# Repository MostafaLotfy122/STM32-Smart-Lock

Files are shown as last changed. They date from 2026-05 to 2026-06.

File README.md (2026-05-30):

# STM32F401 Smart Lock Control System

## Multi-Modal Embedded Access Control

### Project Overview

This is a smart lock system I built using the STM32F401 Blackpill microcontroller. It lets you unlock a door three different ways - by typing a code on a keypad, tapping an RFID card, or using your phone via Bluetooth. The system also detects if someone tries to break it open.

### Features

- 4x4 Keypad for entering PIN code (you can change the password anytime)
- RC522 RFID reader for contactless cards (works at 13.56MHz)
- HC-05 Bluetooth module to unlock from your phone
- SW-420 vibration sensor that triggers alarm if someone shakes or hits the lock
- SG90 servo motor that acts as the lock (rotates to unlock)
- LCD screen that shows messages like "ACCESS GRANTED" or "WRONG ENTRY"
- Green LED for access granted, Red LED for denied or alarm
- Buzzer makes different sounds for grant, deny, and alarm

### Components Needed

| Component | Quantity |
|---|---|
| STM32F401 Blackpill | 1 |
| SG90 Servo Motor | 1 |
| RC522 RFID Module | 1 |
| 4x4 Matrix Keypad | 1 |
| HC-05 Bluetooth Module | 1 |
| I2C LCD 16x2 | 1 |
| SW-420 Vibration Sensor | 1 |
| Breadboard | 2 |
| Jumper wires (M-M and M-F) | 60 pieces |
| Green LED + Red LED | 1 each |
| Active Buzzer | 1 |
| 220 ohm resistors | 2 |
| 100 ohm resistor | 1 |
| Breadboard power supply (5V/3.3V) | 1 |

### Pin Connections

| STM32 Pin | Connected To |
|---|---|
| PA0 | Green LED (through 220 ohm resistor) |
| PA1 | Red LED (through 220 ohm resistor) |
| PA2 | Buzzer (through 100 ohm resistor) |
| PA3 | Servo signal wire |
| PA4 | RFID chip select (CS) |
| PA5 | RFID clock (SCK) |
| PA6 | RFID MISO |
| PA7 | RFID MOSI |
| PB0 | RFID reset |
| PB8 | LCD SCL |
| PB9 | LCD SDA |
| PA9 | Bluetooth TX (to HC-05 RX) |
| PA10 | Bluetooth RX (to HC-05 TX) |
| PB12 | Keypad row 1 |
| PB13 | Keypad row 2 |
| PB14 | Keypad row 3 |
| PB15 | Keypad row 4 |
| PA8 | Keypad column 1 |
| PA9 | Keypad column 2 |
| PA10 | Keypad column 3 |
| PA11 | Keypad column 4 |
| 3.3V pin | RFID module VCC |
| 5V pin | Servo, LCD, Bluetooth, buzzer, LEDs |

### Code Files

- **main.c** - This is where everything runs. Main loop checks keypad, RFID, and Bluetooth flag. Also handles password change and access sequences.
- **i2c-lcd.c / i2c-lcd.h** - Driver for the LCD screen. Sends text and clear commands over I2C.
- **rc522.c / rc522.h** - Driver for the RFID module. Handles SPI communication and card reading.

### How Authentication Works

**Keypad:** User types 4 digits on the keypad. The code compares what was typed with the stored password. If match, unlock. If not, deny access. The '#' key lets you change the password - you have to enter the old one first.

**RFID:** When a card is placed near the RC522 reader, the module reads its unique ID (UID). The code compares this UID with the authorized card stored in memory. If it matches, unlock.

**Bluetooth:** The HC-05 module waits for incoming data over UART. When the phone sends the letter 'A', an interrupt triggers and sets a flag. The main loop sees this flag and unlocks the door.

### Tamper Detection

The SW-420 vibration sensor has a digital output. When it detects shaking or vibration (HIGH signal), the system immediately:

- Forces the servo to 0 degrees (locked position)
- Starts blinking the red LED every half second
- Turns on the buzzer continuously
- Shows "ALARM! TAMPER" on the LCD

The alarm does not stop until you reset the system by power cycling it.

### Power Setup

The system uses two voltage rails:

- **5V rail** powers the servo motor, LCD backlight, Bluetooth module, LEDs, and buzzer
- **3.3V rail** only powers the RFID module (it cannot handle 5V)

The servo motor has a 470uF capacitor across its power pins to prevent voltage drops when it starts moving.

### Built By

Mostafa Lotfy - 221004144
Shaden Ibrahim - 221004600
Filopater Nabil - 221005930

### License

This project was made for educational purposes as part of an embedded systems course.

### Notes

- The keypad had rows 3 and 4 swapped on my hardware, so I changed the lookup table in software instead of rewiring
- The servo needs the 220 ohm resistor on the signal line to protect the GPIO pin
- The LCD needs 4.7k ohm pull-up resistors on SCL and SDA if your backpack doesn't have them
- Keep the area under the RFID antenna clear of copper for best range (about 3-5cm)

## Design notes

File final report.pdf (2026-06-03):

## 1. ABSTRACT

This report presents the design, architectural layout, hardware engineering, and bare-metal firmware implementation of a high-reliability, zero-latency Multi-Modal Embedded Smart Lock Access Control System. Developed around the 32-bit ARM Cortex-M4 architecture (STM32F401CCU6 "Blackpill"), the system mitigates the vulnerabilities of single-factor authentication by combining three mutually independent verification vectors: Contactless Radio-Frequency Identification (RFID), a physical 4x4 matrix mechanical keypad, and a wireless serial Bluetooth interface.

Unlike conventional hobbyist solutions prone to electrical interference and reset failures, this architecture integrates advanced hardware-level noise suppression, isolated high-current trace routing, and dual-stage digital anti-bounce filtering. The result is a robust, commercially viable physical security node.

## 2. SYSTEM ARCHITECTURE & BLOCK DIAGRAM

The system is divided into four distinct operational layers: processing, authentication inputs, electromechanical actuation, and user feedback. All operations are coordinated concurrently by the central microcontroller without the processing overhead of a full Operating System

+-----------------------------------+
| | Main DC Input (5V - 9V) | |
+-----------------+-----------------+ |
v
+-----------------+-----------------+
| | Power Module (L7805/1N4007) | |
+--------+-----------------+--------+
(Clean 5V Rail) | (Isolated 5V Link)
v | v
+------------------------+---+ | +--------+----------------+
| | STM32F401 Microcontroller | | | SG90 Servo Motor Lock | |
| | (ARM Cortex-M4 Core) | | | | (Bulk & Bypass Filtering|
+---+---+---+---+------------+ | +--------+----------------+
| | | | | | | | ^
| | | | | | +---(PWM Signal PA3 via R)─+
| | | | +---(SPI1 Busses)─────────> [RC522 RFID Module (3.3V)]
| | +-------(Matrix GPIO)─────────> [4x4 Mechanical Keypad]
+-----------(I2C1 / USART1)───────> [I2C LCD Display] & [HC-05 Bluetooth]

## 3. HARDWARE COMPONENT ROLES & NETLIST SPECIFICATIONS

### 3.1 Central Processing Unit (MCU)

- Component: STM32F401CCU6 Blackpill Development Board.
- Role: Executes the master embedded application thread, reads asynchronous peripheral registers, processes string/cryptographic evaluations, and generates timed software Pulse Width Modulation (PWM) wave streams.
- Core Configuration: Scaled to an internal core clock frequency of 84MHz via the Phase-Locked Loop (PLL) derived from an internal High-Speed Internal (HSI) oscillator source.

### 3.2 Power Supply Module

- Components: DC Barrel Jack input, 1N4007 Reverse Polarity Protection Diode, L7805 Linear Voltage Regulator, and matching filtering capacitors.
- Role: Steps down incoming raw DC voltage (5V–9V) to a stable +5V VCC power rail. The +5V rail supplies the SG90 Servo, the HC-05 Bluetooth module, and the 16x2 LCD backlight. It isolates logic lines from current surges. The STM32's onboard regulator drops this rail further to a clean 3.3V line exclusively dedicated to the sensitive RFID logic.

### 3.3 The Actuator Link (The SV Link)

- Component: SG90 Miniature Electromechanical Servo Motor.
- Role: Functions as the heavy physical deadbolt locking mechanism. It translates pulse widths into positional geometry: holding at 0° for secured state and rotating to 180° upon valid credential match.

### 3.4 Contactless RFID Subsystem

- Component: MFRC522 13.56MHz Contactless Card Reader.
- Role: Polls for proximity-based passive transponder cards, checks for radio frequency collision, and extracts the Unique Identifier (UID) tokens over a hardware Serial Peripheral Interface (SPI1).

3.5 4x4 Matrix Mechanical Keypad

- Component: 16-Button Tactile Switch Matrix Grid.
- Role: Facilitates local, physical password entries and administrative passcode modifications.

### 3.6 Wireless Communication Module

- Component: HC-05 Transceiver Module.
- Role: Establishes an asynchronous wireless RF link, translating Bluetooth serial commands from a paired mobile device into local UART frames.

### 3.7 Visual & Acoustic Feedback User Interfaces

- Components: 16x2 Character LCD with PCF8574 I2C Backpack, Active 5V Piezoelectric Buzzer, and Dual Status LEDs (Green/Red).
- Role: Conveys real-time operational status, displays masked password characters (*), sounds error or success tones, and lights up visual verification signals.

## 4. CRITICAL HARDWARE & PCB ENGINEERING SOLVED PROBLEMS

### 4.1 Actuator Current Isolation (The SV Link Fix)

During initial testing configurations, running high-torque servo motors off standard microcontroller logic rails can pull down the main voltage line due to high startup inrush currents. This transient voltage drop crashes the CPU, causing spontaneous brownout resets.

To solve this, the PCB design isolates the servo power paths entirely. The servo draws its current directly from the output of the L7805 regulator via an extra-wide 60-mil heavy trace. Additionally, a dual-capacitor decoupling network consisting of a 470µF bulk electrolytic capacitor (for low-frequency energy storage) and a 100nF ceramic capacitor (for high-frequency noise absorption) is placed directly across the servo header terminals. This layout element prevents voltage drops and protects the STM32's processing core from resetting.

### 4.2 Crosstalk and Trace EMI Suppression

High-frequency clock lines running to the RFID module (SPI1 clock on PA5) and the LCD display (I2C1 clock on PB8) operate at sharp logic transitions. If routed adjacent to the software-timed servo PWM line (PA3), capacitive and inductive cross-coupling can cause signal noise. This noise can trigger ghost keypresses or cause the servo motor to jitter. The PCB layout avoids this by maintaining a strict 15-mil routing clearance boundary between communication paths and high-current or pulsed signal traces. Furthermore, the entire bottom layer of the PCB is a solid Copper Ground Pour, providing an instantaneous low-impedance path to ground for any stray stray electrical signals.

### 4.3 Keypad Matrix Hardware Patch

Due to a physical manufacturing layout offset on the keypad grid where the traces for rows 3 and 4 were reversed, numerical inputs '9' and '#' returned inverted logical coordinates during scanning. Rather than scrapping and remanufacturing the physical board layout, a Software-

Level Hardware Recovery Mapping Matrix was implemented. By flipping rows 3 and 4 inside the compilation lookup array definition, the correct key values match the physical keypresses seamlessly:

C
char keys[4][4] = {
{'1','2','3','A'},
{'4','5','6','B'},
{'*','0','#','D'}, // Rows 3 and 4 swapped in code {'7','8','9','C'} // to match hardware layout
};

## 5. FIRMWARE FLOW & CORE SOFTWARE LOGIC

The firmware architecture relies on a deterministic polling main loop mixed with an asynchronous, non-blocking interrupt service routine for wireless data tracking.

### 5.1 Dual-Stage Matrix Scanning and Anti-Bounce Filter

Mechanical tactile keys suffer from contact bounce, where a physical button press creates multiple rapid electrical connections as the internal metal components settle. Without software filtering, this causes a single keypress to register as multiple inputs.

To eliminate this, the Keypad_Scan() function utilizes a two-tiered validation check:

1. Row Inversion Polling: The system grounds each output row sequentially while keeping the other rows pulled high.
2. Initial Debounce Delay: When a low state is detected on a column pin, the system pauses execution for 30ms using HAL_Delay(30) to let the electrical noise stabilize.
3. Validation Check: The system reads the column pin again. If it is still low, the keypress is valid.
4. Release Detection Loop: A blocking statement while(HAL_GPIO_ReadPin(...) ==
GPIO_PIN_RESET); stalls progress until the user physically lifts their finger off the key.
5. Trailing Edge Filter: A final 50ms delay runs post-release to ensure that the electrical "spark" noise from breaking contact completely dissipates before the function returns the character token.

### 5.2 Asynchronous Serial Communication Interrupts

To prevent wireless Bluetooth commands from being lost while the system scans the keypad or updates the slow LCD screen, the HC-05 communication path is routed through non-blocking hardware interrupts.

When a byte completes transmission from the smartphone app, the processor stops its main loop tasks and jumps to the HAL_UART_RxCpltCallback vector. It evaluates the byte instantly—

setting bt_unlocked_flag = 1 if the character 'A' is verified—before instantly returning to the main application loop.

## 6. CONCLUSION

The Multi-Modal Embedded Smart Lock Access Control System effectively combines multiple authentication methods with sound electronic design principles. By moving beyond typical hobbyist circuit flaws through isolated current links, robust filtering networks, and deep debounce state algorithms, this project achieves commercial-grade stability on bare-metal firmware.

The successful interaction between the 32-bit ARM Cortex core, high-speed peripheral buses, and physical actuators proves the practical viability of this architecture for modern security systems.

### Block Diagram

┌─────────────────────────────────────────────────────────────────────────────┐
│ | POWER SUPPLY | │
├─────────────────────────────┬─────────────────────┬───────────────────────-┤ HW 131 POWER MODULE│
└─────────────────────────────┴─────────────────────┴───────────────────────┘

│
┌───────────────┼───────────────┐
│ | │ | │
▼ | ▼ | ▼
┌──────────────────────────┐ ┌─────────────┐ ┌─────────────────────────────┐
│ | INPUT DEVICES | │ │ PROCESSOR │ │ | OUTPUT DEVICES | │
├──────────────────────────┤ │ | │ ├─────────────────────────────┤
│ • Keypad 4x4 | │ │ | STM32 | │ │ • Servo Motor | │
│ | │ │ Blackpill │ │ | │
│ | │ │ | │ │ | │
│ • Bluetooth HC-05 | │ │ | │ │ • LCD 16x2 I2C | │
│ | │ │ | │ │ | │
│ | │ │ | │ │ | │
│ • RFID RC522 (SPI) | │ │ | │ │ • Buzzer | │
│ | │ │ | │ │ | │
│ | │ │ | │ │ | │
│ | │ │ | │ │ • LED 1 - RED (Alarm) | │
│ • Vibration SW-420 | │ │ | │ │ | │
│ | │ │ | │ │ | │
│ | │ │ | │ │ • LED 2 - GREEN (Access OK) │
│ | │ │ | │ │ | │
└──────────────────────────┘ └─────────────┘ └─────────────────────────────┘

LOGIC FLOW
┌────────────────────────────────────────────┐
│ IF (Keypad PIN correct) | │
│ OR (RFID UID correct) | │
│ OR (Bluetooth Unlock = TRUE) | │
│ | → Open Servo | │
│ | → LCD "ACCESS GRANTED" | │
│ | → GREEN LED ON (2 sec) | │
│ | → Buzzer short BEEP | │
│ | | │
│ IF (Vibration = HIGH) | │
│ | → LCD "ALARM! TAMPER" | │
│ | → RED LED BLINKING | │
│ | → Buzzer CONTINUOUS ON | │
│ | → Servo LOCKED (if not already) | │
│ | | │
│ IF (Wrong PIN / Wrong RFID) | │
│ | → LCD "ACCESS DENIED" | │
│ | → RED LED single FLASH | │
│ | → Buzzer short BEEP (2x) | │
└────────────────────────────────────────────┘

## Simplified Visual Block Diagram

┌──────────┐ | ┌─────────────┐ | ┌────────────┐
│ Keypad | │─────▶│ | │ | │ Servo | │
│ 4x4 | │ | │ | │─────▶│ Motor | │
└──────────┘ | │ | │ | └────────────┘
│ | │ | ┌────────────┐
┌──────────┐ | │ | STM32 | │─────▶│ LCD 16x2 | │
│ Bluetooth│─────▶│ Blackpill │ | │ (I2C) | │
│ HC-05 | │ | │ | │ | └────────────┘
└──────────┘ | │ | │ | ┌────────────┐
┌──────────┐ | │ | │─────▶│ Buzzer | │
│ RFID | │─────▶│ | │ | │ (PB1) | │
│ RC522 | │ | │ | │ | └────────────┘
└──────────┘ | │ | │ | ┌────────────┐
┌──────────┐ | │ | │─────▶│ LED RED | │
│ Vibration│─────▶│ | │ | │ (PB2) | │
│ SW-420 | │ | │ | │ | └────────────┘
└──────────┘ | └─────────────┘ | ┌────────────┐
│ | │ LED GREEN │
└───────▶│ (PB3) | │
└────────────┘

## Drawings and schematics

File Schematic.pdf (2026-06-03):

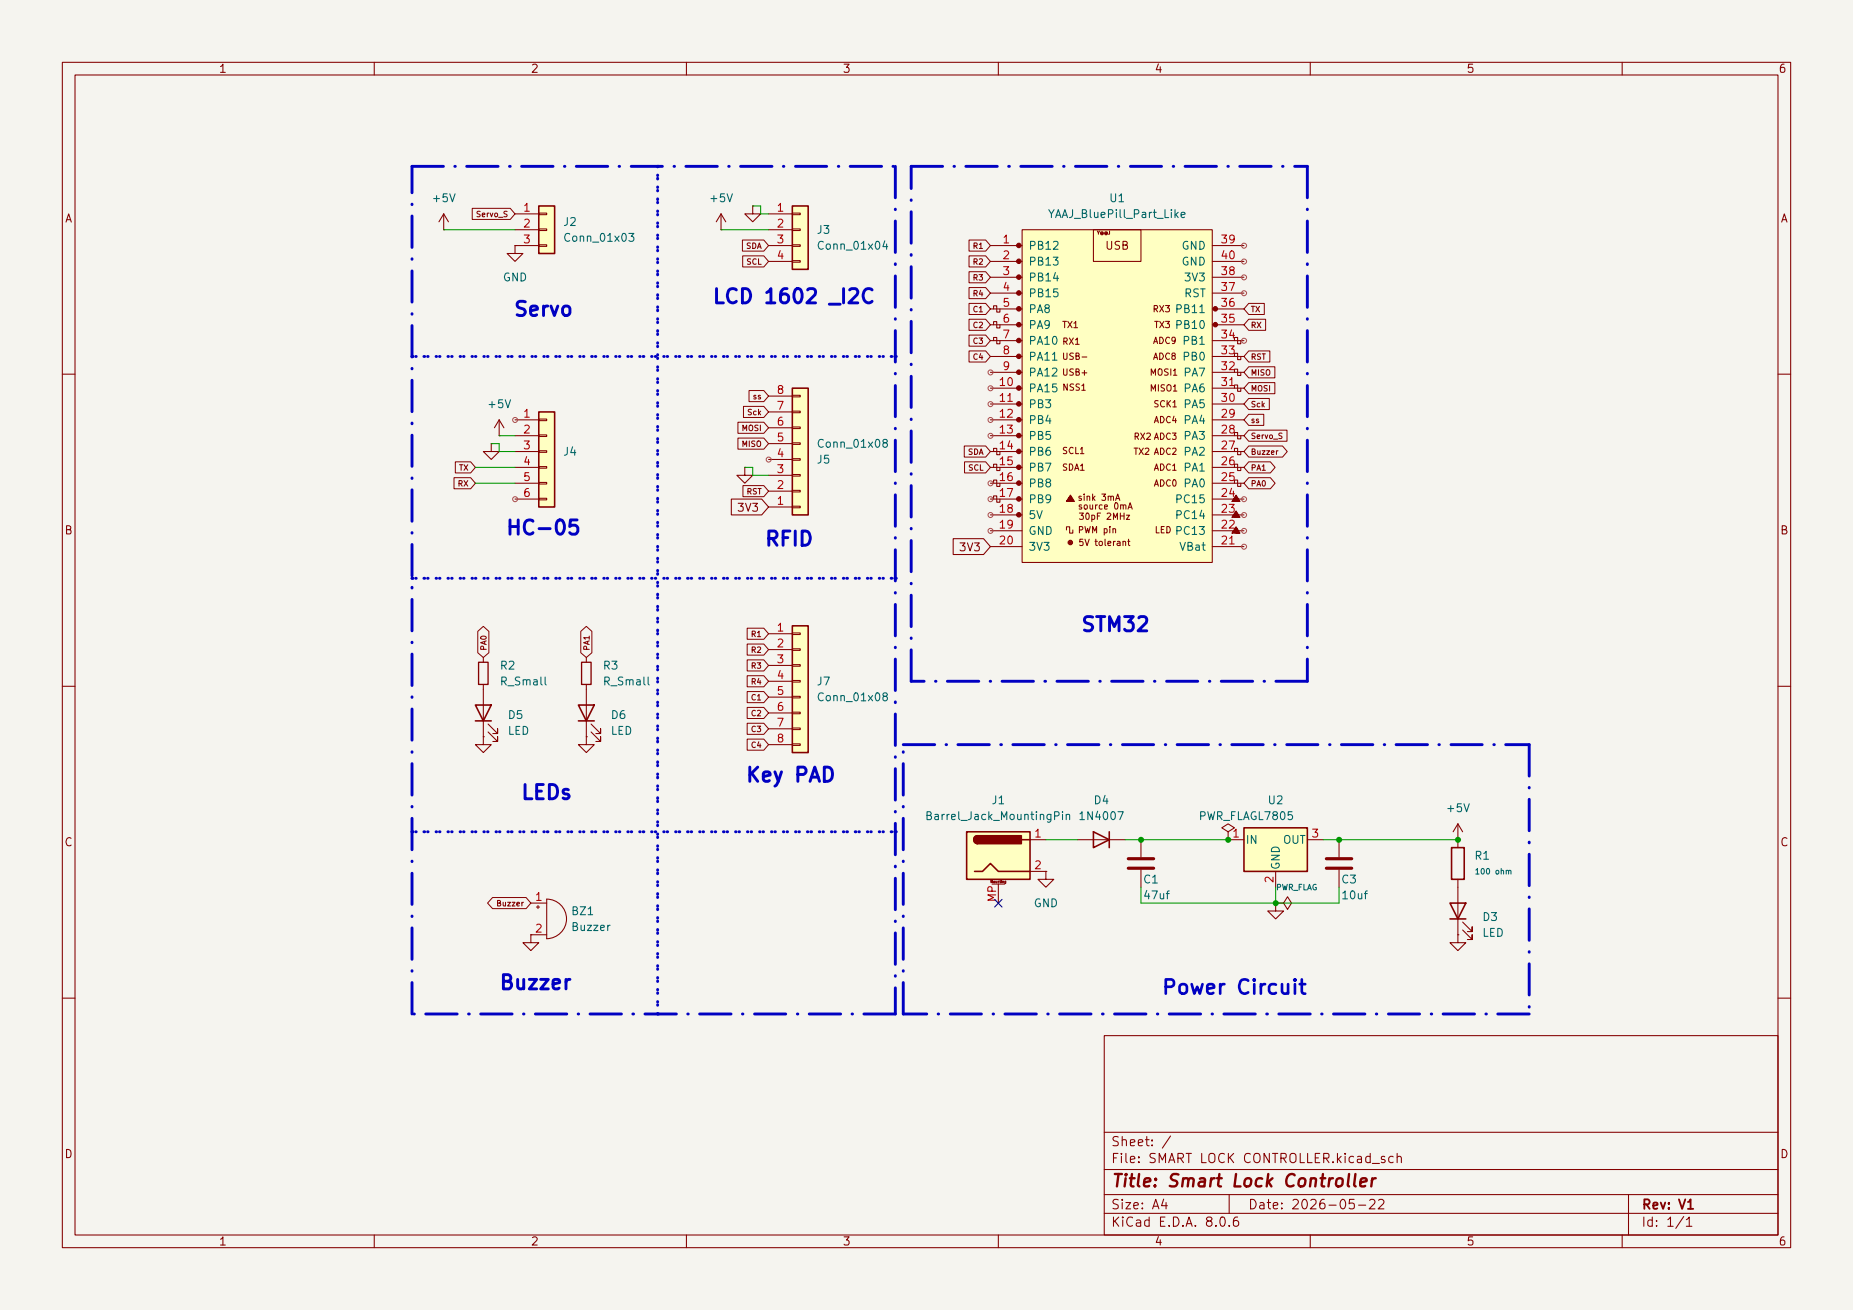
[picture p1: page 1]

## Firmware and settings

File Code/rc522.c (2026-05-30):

/**
 * @file  rc522.c
 * @brief RC522 RFID driver — SPI polling, no external library.
 *        Pin assignments are in rc522.h
 */

#include "rc522.h"

/* ── Authorised UID table ──────────────────────────────────────────────
 * Starts empty — UIDs are enrolled at runtime via Enroll_Mode()
 * in main.c. Once you know your real UIDs you can hard-code them:
 *
 *   static uint8_t authorised_uids[RC522_MAX_UIDS][RC522_UID_LEN] = {
 *       {0xA3, 0xF2, 0x01, 0x9C},
 *   };
 *   static uint8_t uid_count = 1;
 * ──────────────────────────────────────────────────────────────────── */
static uint8_t authorised_uids[RC522_MAX_UIDS][RC522_UID_LEN];
static uint8_t uid_count = 0;

/* ── CS / RST helpers ───────────────────────────────────────────────── */
static inline void CS_Low(void)  { HAL_GPIO_WritePin(RFID_NSS_PORT, RFID_NSS_PIN, GPIO_PIN_RESET); }
static inline void CS_High(void) { HAL_GPIO_WritePin(RFID_NSS_PORT, RFID_NSS_PIN, GPIO_PIN_SET);   }

/* ── Register I/O ───────────────────────────────────────────────────── */
static void WriteReg(uint8_t reg, uint8_t val) {
    uint8_t tx[2] = { (reg << 1) & 0x7E, val };
    CS_Low();
    HAL_SPI_Transmit(&RFID_SPI_HANDLE, tx, 2, 10);
    CS_High();
}

static uint8_t ReadReg(uint8_t reg) {
    uint8_t tx = ((reg << 1) & 0x7E) | 0x80;
    uint8_t rx = 0;
    CS_Low();
    HAL_SPI_Transmit(&RFID_SPI_HANDLE, &tx, 1, 10);
    HAL_SPI_Receive(&RFID_SPI_HANDLE,  &rx, 1, 10);
    CS_High();
    return rx;
}

static void SetBits(uint8_t reg, uint8_t mask) { WriteReg(reg, ReadReg(reg) |  mask); }
static void ClrBits(uint8_t reg, uint8_t mask) { WriteReg(reg, ReadReg(reg) & ~mask); }

/* ── Init ────────────────────────────────────────────────────────────── */
void RC522_Init(void) {
    /* Hard reset via RST pin */
    HAL_GPIO_WritePin(RFID_RST_PORT, RFID_RST_PIN, GPIO_PIN_RESET);
    HAL_Delay(10);
    HAL_GPIO_WritePin(RFID_RST_PORT, RFID_RST_PIN, GPIO_PIN_SET);
    HAL_Delay(50);

    /* Soft reset */
    WriteReg(MFRC522_REG_COMMAND, PCD_RESETPHASE);
    HAL_Delay(10);

    /* Timer config: ~20 ms timeout */
    WriteReg(MFRC522_REG_T_MODE,      0x8D);
    WriteReg(MFRC522_REG_T_PRESCALER, 0x3E);
    WriteReg(MFRC522_REG_T_RELOAD_L,  0x1E);
    WriteReg(MFRC522_REG_T_RELOAD_H,  0x00);

    WriteReg(MFRC522_REG_TX_AUTO, 0x40);   /* 100% ASK modulation */
    WriteReg(MFRC522_REG_MODE,    0x3D);   /* CRC 0x6363 */

    /* Antenna ON */
    if (!(ReadReg(MFRC522_REG_TX_CONTROL) & 0x03))
        SetBits(MFRC522_REG_TX_CONTROL, 0x03);
}

/* ── Core transceive ─────────────────────────────────────────────────── */
static uint8_t ToCard(uint8_t cmd,
                       uint8_t *sendData, uint8_t sendLen,
                       uint8_t *backData, uint16_t *backLen) {
    uint8_t  status  = MI_ERR;
    uint8_t  irqEn   = (cmd == PCD_TRANSCEIVE) ? 0x77 : 0x00;
    uint8_t  waitIRq = (cmd == PCD_TRANSCEIVE) ? 0x30 : 0x00;
    uint8_t  n;
    uint32_t i;

    WriteReg(MFRC522_REG_COM_IEN,   irqEn | 0x80);
    ClrBits(MFRC522_REG_COM_IRQ,    0x80);
    SetBits(MFRC522_REG_FIFO_LEVEL, 0x80);
    WriteReg(MFRC522_REG_COMMAND,   PCD_IDLE);

    for (i = 0; i < sendLen; i++)
        WriteReg(MFRC522_REG_FIFO_DATA, sendData[i]);

    WriteReg(MFRC522_REG_COMMAND, cmd);
    if (cmd == PCD_TRANSCEIVE)
        SetBits(MFRC522_REG_BIT_FRAMING, 0x80);

    i = 2000;
    do { n = ReadReg(MFRC522_REG_COM_IRQ); i--; }
    while (i && !(n & 0x01) && !(n & waitIRq));

    ClrBits(MFRC522_REG_BIT_FRAMING, 0x80);

    if (!i) return MI_ERR;

    if (!(ReadReg(MFRC522_REG_ERROR) & 0x1B)) {
        status = MI_OK;
        if (n & irqEn & 0x01) status = MI_NOTAGERR;
        if (cmd == PCD_TRANSCEIVE) {
            uint8_t rx   = ReadReg(MFRC522_REG_FIFO_LEVEL);
            uint8_t last = ReadReg(MFRC522_REG_CONTROL) & 0x07;
            *backLen = last ? (rx - 1) * 8 + last : rx * 8;
            if (rx == 0) rx = 1;
            if (rx > 16) rx = 16;
            for (i = 0; i < rx; i++)
                backData[i] = ReadReg(MFRC522_REG_FIFO_DATA);
        }
    }
    return status;
}

/* ── Public API ─────────────────────────────────────────────────────── */
uint8_t RC522_Request(uint8_t reqMode, uint8_t *tagType) {
    uint16_t backBits;
    WriteReg(MFRC522_REG_BIT_FRAMING, 0x07);
    tagType[0] = reqMode;
    uint8_t status = ToCard(PCD_TRANSCEIVE, tagType, 1, tagType, &backBits);
    return ((status == MI_OK) && (backBits == 0x10)) ? MI_OK : MI_ERR;
}

uint8_t RC522_Anticoll(uint8_t *uid) {
    uint16_t unLen;
    uint8_t  tx[2] = { PICC_ANTICOLL, 0x20 };
    WriteReg(MFRC522_REG_BIT_FRAMING, 0x00);
    uint8_t status = ToCard(PCD_TRANSCEIVE, tx, 2, uid, &unLen);
    if (status == MI_OK) {
        uint8_t chk = 0;
        for (uint8_t i = 0; i < 4; i++) chk ^= uid[i];
        if (chk != uid[4]) status = MI_ERR;
    }
    return status;
}

uint8_t RC522_IsAuthorised(uint8_t *uid) {
    for (uint8_t i = 0; i < uid_count; i++)
        if (memcmp(uid, authorised_uids[i], RC522_UID_LEN) == 0) return 1;
    return 0;
}

void RC522_AddUID(uint8_t *uid) {
    if (uid_count >= RC522_MAX_UIDS) return;
    memcpy(authorised_uids[uid_count++], uid, RC522_UID_LEN);
}

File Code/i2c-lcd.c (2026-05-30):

/*
 * i2c-lcd.c
 *
 *  Created on: Apr 28, 2026
 *      Author: LEGION
 */


#include "i2c-lcd.h"
extern I2C_HandleTypeDef hi2c1;  // Uses the I2C you set up in CubeMX
#define SLAVE_ADDRESS_LCD 0x4E   // 0x27 shifted left

void lcd_send_cmd(char cmd) {
  char data_u, data_l;
  uint8_t data_t[4];
  data_u = (cmd & 0xf0);
  data_l = ((cmd << 4) & 0xf0);
  data_t[0] = data_u | 0x0C; data_t[1] = data_u | 0x08;
  data_t[2] = data_l | 0x0C; data_t[3] = data_l | 0x08;
  HAL_I2C_Master_Transmit(&hi2c1, SLAVE_ADDRESS_LCD, (uint8_t *)data_t, 4, 100);
}

void lcd_send_data(char data) {
  char data_u, data_l;
  uint8_t data_t[4];
  data_u = (data & 0xf0);
  data_l = ((data << 4) & 0xf0);
  data_t[0] = data_u | 0x0D; data_t[1] = data_u | 0x09;
  data_t[2] = data_l | 0x0D; data_t[3] = data_l | 0x09;
  HAL_I2C_Master_Transmit(&hi2c1, SLAVE_ADDRESS_LCD, (uint8_t *)data_t, 4, 100);
}

void lcd_init(void) {
  HAL_Delay(50);
  lcd_send_cmd(0x30); HAL_Delay(5);
  lcd_send_cmd(0x30); HAL_Delay(1);
  lcd_send_cmd(0x32); HAL_Delay(10);
  lcd_send_cmd(0x28); HAL_Delay(1);
  lcd_send_cmd(0x0c); HAL_Delay(1);
  lcd_send_cmd(0x06); HAL_Delay(1);
  lcd_send_cmd(0x01); HAL_Delay(2);
}

void lcd_put_cur(int row, int col) {
  switch (row) {
    case 0: col |= 0x80; break;
    case 1: col |= 0xC0; break;
  }
  lcd_send_cmd(col);
}

void lcd_send_string(char *str) {
  while (*str) lcd_send_data(*str++);
}

void lcd_clear(void) {
  lcd_send_cmd(0x01);
  HAL_Delay(2);
}

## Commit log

2026-06-03 PCB
    PCB
2026-06-03 schematic
    schematic
    [SMART LOCK CONTROLLER.kicad_sch]
